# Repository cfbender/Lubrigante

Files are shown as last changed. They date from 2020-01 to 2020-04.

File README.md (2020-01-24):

# Lubrigante

_A TGR Alice Acrylic Case Revision By Zambumon with addition of Ergosaurus support by cfbender (waxpoetik)_

### This repo is a fork of the original Lubrigante repo, intended to add support for the Ergosaurus PCB made by /u/reggatronics. It uses an extra spacing layer and a modified plate for the layout. Please read the available layouts section for details.

### CHECK THE ISSUES TAB BEFORE MAKING THIS CASE

Lubrigante

The aim of this project is to revisit the TGR Alice acrylic case (designed by Yuktsi), and host a guide with some basic resources so you can make your own.

You can find Yuktsi's original case files [here](https://geekhack.org/index.php?topic=95054.msg2661499#msg2661499).

### Differences between Lubrigante and Alice

- 4mm corners and a smaller footprint
- Top piece opening has now round corners instead of sharp ones
- Compatible with screw-in stabs.
- Fixed layout both for half-plate and full-plate.

# Disclaimer

**THIS IS A WORK IN PROGRESS PROJECT. USE THE FILES AT YOUR OWN RISK**

## Available layouts:

- **MAN OF LAYOUTS**: fixed layout. Stepped caps lock, 2.00U space bar next to a 1.25U modifier, standard backspace.
  - **Half plate**
  - ~~**Full plate**~~ _reworking_

- **ERGOSAURUS- Angled**: flexible layout. ANSI Caps lock or Stepped caps lock, 2.00U space bar next to a 1.25U modifier OR 2.25u space bar next to a 1u modifier, split or standard backspace.
  - **Half plate**
  - 
- **ERGOSAURUS- Flat front**: flexible layout. ANSI Caps lock or Stepped caps lock, 2.00U space bar next to a 1.25U modifier, split or standard backspace.
  - **Half plate**
  
---

## Making the case

Wherever you use the files, make sure to **set the scale to millimetres**. **The keyboard should be 348.8mm wide.**

The case is made with multiple layers of acrylic that are stacked on top of each other and held together with 8 M3 screws. Each file has 5 distinct pieces:
- **Piece A - Top opening**: this is the top piece of the of the case, the one with two openings. This piece is placed on top of the plate.
- **Piece B - Plate**: used to hold the switches, it is the one with switch and stab holes. On the left side lower corner it has a slot for the LEDs.
- **Piece C - Upper USB**: this piece is placed right under the plate and it is necessary for 3mm or lower plates. With a 5mm plates, you won't need it.
- **Piece D - Lower USB***: meant to be placed right on top of the bottom piece, the only difference with **Piece C** is the lack of an exit for the USB port.
- **Piece E - Bottom piece**: the one that closes the case. It has 3 M4 holes so you can install either 3 cone feet.

### Layer thicknesses: what are your alternatives?

- **3mm pieces**: probably the most versatile solution, as there are lots of acrylic finishes and it is the one I used while prototyping. It consists on **6 layers** of 3mm acrylic: 2x Piece A, 1x Piece B, 1x Piece C, 1x Piece D, and 1x Piece E.
- **5mm pieces**: this might look in the beginning as a more cost effective solution, but that might not be the case. The shop will probably use a bigger kerf to make the pieces, and that would be problematic for both most of them, specially the plate. If you decide to go with this route, there are two possibilities:
  - 1x Piece A, 1x Piece B, 1x Piece D, 1x Piece E.
  - 1x Piece A, 1x Piece C, 1x Piece D, 1x Piece E + a non-acrylic 1.5mm Piece B (either aluminum, brass, copper, carbon fiber, etc.).
- **The TGR way**: The original case used 3 different acrylic thicknesses: an 8mm Piece A, 5mm Piece B, 5mm Piece D, and 3mm Piece E. It had 8 countersunk M3 holes: 8 on Piece A, and two M4 countersunk on the Piece E. Additionally, its Piece E had 8 of its screw holes tapped.
- **Mix of 3mm and 5mm layers**: one possibility could be 1x 3mm Piece A, 1x 5mm Piece A, 1x 3mm Piece B, 1x 5mm Piece C, 1x 3mm Piece D, 1x 3mm Piece E.

Lubrigante

###  Ordering the acrylic pieces

There are a handful of ways of getting the acrylic pieces done:
- Contacting a local maker spaces or a laser cutting shop.
- Ordering online:
  - [Ponoko](https://www.ponoko.com) (NA)
  - [Formulor](https://www.formulor.de) (EU) I have used their service for the prototype. Shipping will be expensive as they have to use a large sheet of acrylic, so ordering multiple cases is recommended. The case will end up costing around 75 EUR + shipping.

### Other components

- PCB: you can use the original TGR Alice PCB or the one [Maarten Dekkers](https://github.com/Maartenwut) has designed and that will be available for purchase soon.
- [CNCd aluminum cone feet](http://lmgtfy.com/?q=cnc+aluminum+cone+feet). These will most likely come with M4 screws.
- Bumpons: I recommend using some `SJ5302 3M`, as these are very similar to the ones used by the CNCd cone feet.
- Screws:
  - 8x M3 20mm screws. The original acrylic TGR Alice used flat head nylon screws. I've used some hex socket screws. If you plan to use some nuts to hold the screws, you might need to use longer screws.

Lubrigante

---

## License

This repository is under the [GNU GPL V3 license](./LICENSE). If you plan to sell these cases, make sure to read it.

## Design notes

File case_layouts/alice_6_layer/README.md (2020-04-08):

# Alice 6 Layer

This isn't really the Ergosaurus per se, nor is it the Lubrigante of which the Ergosaurus is based on. I am putting this design up as an angled front Lubrigante with a more high compatibility plate, that people can easily order from Ponoko. 

Note: This case will not work with the Ergosaurus PCB due to clearance issues with the pro micro. It should work for most Alice PCBs, the same as the Lubrigante. When you upload it to Ponoko the dimensions should read 348.8 mm wide.

If you want a simple color, and want to use M3x20 screws, that's gonna be your best bet. Stop paying 420 Euros for acrylic cases.

At the time of this upload, here are the prices from Ponoko if you want to order it yourself:
ponoko acrylic prices

As low as $45! There will be a $9 one-time setup fee, but with multiple item discounts, if you find someone to go in on it with you, it essentially goes away. Hope this helps someone.

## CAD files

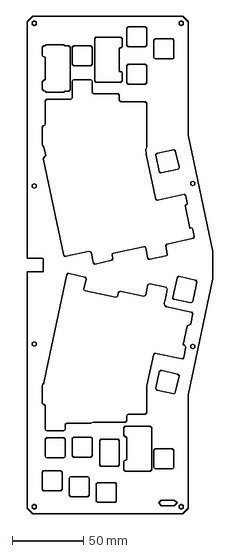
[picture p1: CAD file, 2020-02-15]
case_layouts/ergosaurus/angled/L4.dxf
130.3 x 348.8 mm

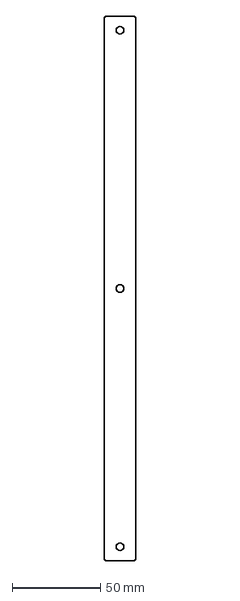
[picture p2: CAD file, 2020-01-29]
case_layouts/ergosaurus/feet/F2.dxf
18.0 x 308.2 mm

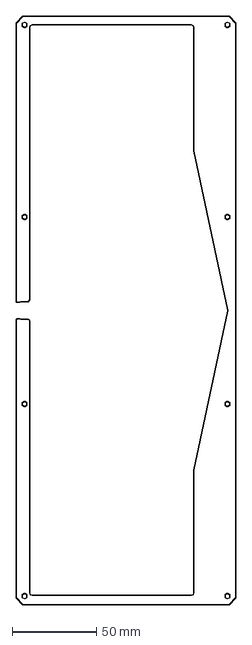
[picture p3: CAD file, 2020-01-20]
case_layouts/ergosaurus/flat-front/L3.dxf
130.2 x 348.8 mm

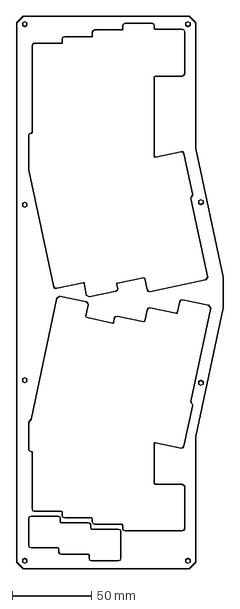
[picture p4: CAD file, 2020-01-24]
case_layouts/ergosaurus/angled/L6.dxf
130.3 x 348.8 mm

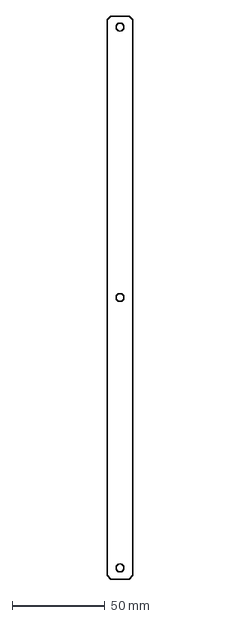
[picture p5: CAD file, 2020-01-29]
case_layouts/ergosaurus/feet/F1.dxf
14.0 x 304.2 mm

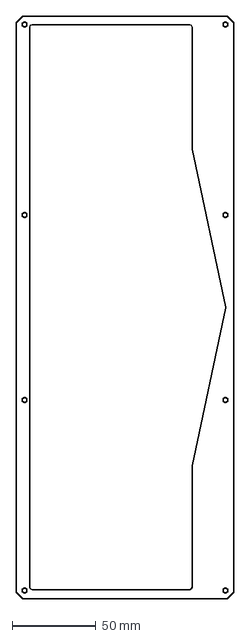
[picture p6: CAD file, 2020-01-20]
case_layouts/ergosaurus/flat-front/L1.dxf
130.2 x 348.8 mm

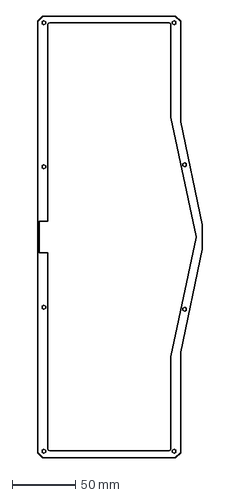
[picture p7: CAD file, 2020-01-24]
case_layouts/ergosaurus/angled/L2_bob_cutout.dxf
130.3 x 348.8 mm

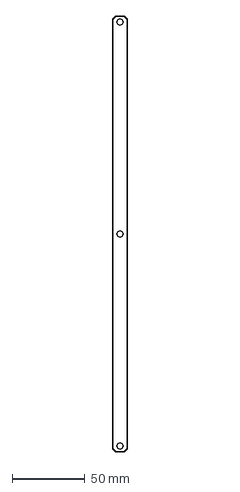
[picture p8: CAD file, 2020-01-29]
case_layouts/ergosaurus/feet/F0.dxf
10.0 x 300.2 mm

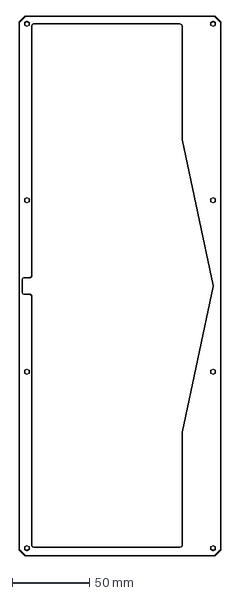
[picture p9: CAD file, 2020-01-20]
case_layouts/ergosaurus/flat-front/L2.dxf
130.2 x 348.8 mm

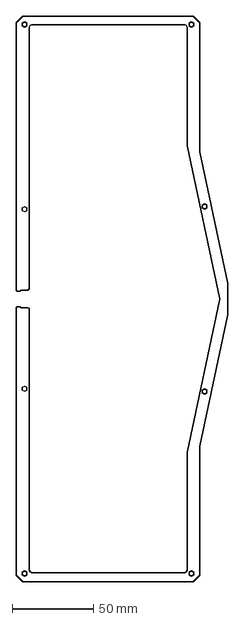
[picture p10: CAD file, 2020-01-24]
case_layouts/ergosaurus/angled/L3.dxf
130.3 x 348.8 mm

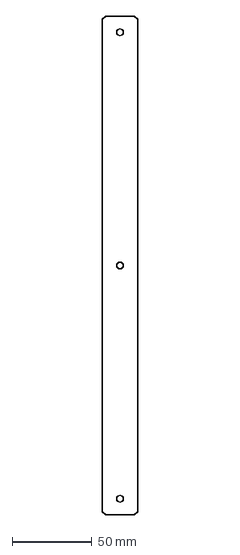
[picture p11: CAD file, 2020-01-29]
case_layouts/ergosaurus/feet/F3.dxf
22.0 x 312.2 mm

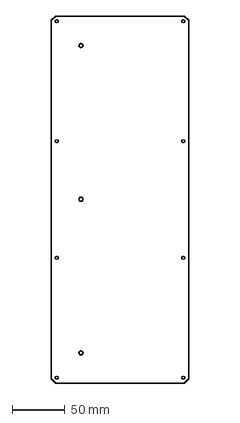
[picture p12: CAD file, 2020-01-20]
case_layouts/ergosaurus/flat-front/L0.dxf
130.2 x 348.8 mm

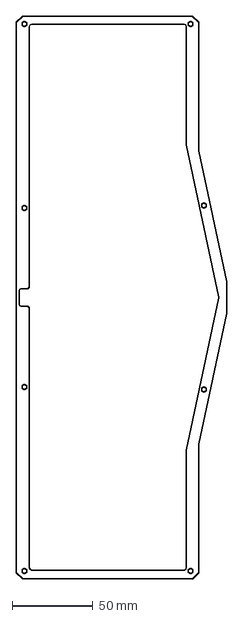
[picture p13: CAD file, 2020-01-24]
case_layouts/ergosaurus/angled/L2.dxf
130.3 x 348.8 mm

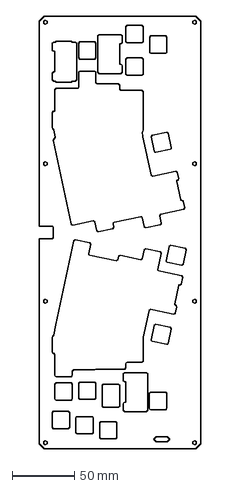
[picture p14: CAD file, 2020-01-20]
case_layouts/ergosaurus/flat-front/L4.dxf
130.3 x 348.8 mm

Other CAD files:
case_layouts/ergosaurus/angled/L5.dxf
case_layouts/ergosaurus/flat-front/L5.dxf
case_layouts/ergosaurus/angled/L0.dxf
case_layouts/ergosaurus/flat-front/L6.dxf
case_layouts/ergosaurus/angled/L1.dxf

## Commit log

2019-12-29 First draft of ergosaurus layout
    [ergosaurus_case.dxf]
2019-12-30 Added split and combined files
    [ergosaurus_case.dxf, ergosaurus_half_plate_3mm_combined.dxf]
2020-01-20 Add individual files
    [L0.dxf, L1.dxf, L2.dxf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]
2020-01-22 Add angled files
    [L0.dxf, L1.dxf, L2.dxf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]
2020-01-24 Add 2.25u space support
    [L4.dxf]
2020-01-29 Add Case feet
    [F0.dxf, F1.dxf, F2.dxf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]
2020-02-15 Fix plate and update Ponoko files
    [L4.dxf]
2020-04-08 Add alice 6 layer case
